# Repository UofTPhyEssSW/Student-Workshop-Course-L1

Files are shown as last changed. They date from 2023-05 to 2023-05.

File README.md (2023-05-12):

# Student-Workshop-Course-L1



<p>
This is a non-credit Introduction to Electronics Graduate course for University of Toronto, Physics Gradute students, held over four, three-hour sessions which consist of one hour of lecture and two hours of practical time.
</p>

## Course Summary

<p>
This course is an Introduction to Electronics course where the student will learn how to solder through hole and surface mount components as well as learn about data acquisition (DAQ), power supplies, digital and analog electronics circuits. During the course the students will build a single channel DAQ board that measures ambient temperature and an Arduino Uno clone, which is theirs to take home. Please note that class has a maximum of 4 students and must have a minimum of 2 students registered for the class to be held.

If the class is full and your are still interested, please add yourself to the waiting list. We will try to schedule another course as soon as possible.
</p>

<a href="https://plrs.physics.utoronto.ca/course-listing/">Available Courses</a>

# Aruduino Framework
<p>
The Arduino IDE 2 is used to demostrate the Phyduino Pico and Analog Front End board. Since these are custom boards a new board manager and libraries must be installed in the IDE for the boards to be programmed. (<a href="https://docs.arduino.cc/software/ide-v2/tutorials/ide-v2-board-manager">instructions here</a>). 
</p>

# Required Arduino Libraries 
- <a href="https://github.com/sparkfun/SparkFun_STUSB4500_Arduino_Library/tree/7f76188b7900d930aeb7908319d463b6446257c6">Sparkfun STUSB4500 Arduino library</a>
- <a href="https://github.com/UofTPhyEssSW/Student-Workshop-Course-L1/tree/main/arduino/libraries/max11635_adc">MAX11635 ADC Arduino Libray</a>
- <a href="https://github.com/UofTPhyEssSW/Student-Workshop-Course-L1/tree/main/arduino/libraries/phyduino_pico">Phyduino Board Library</a>
- <a href="https://github.com/UofTPhyEssSW/Student-Workshop-Course-L1/tree/main/arduino/libraries/Analog_Front_End_Arduino_Library">Analog Front End Arduino Library</a>
- <a href="https://github.com/mathertel/RotaryEncoder">Rotary Encoder Library</a>
# Hardware 

<p>
All circuit boards for this course were designed using <a href="https://www.kicad.org/">KiCad EDA</a> opensource software to make the schematic and PCB design files easy to access for the student. It's not requirement for the student to understand schematic symbols or PCB design the files are there for reference.
</p>

## Boards

- <a href="https://github.com/UofTPhyEssSW/Student-Workshop-Course-L1/tree/main/hardware/phyduino_pico">Phyduino Pico Microcontroller board</a>
- <a href="https://github.com/UofTPhyEssSW/Student-Workshop-Course-L1/tree/main/hardware/analog_front_end_shield">Analog Front End board</a>

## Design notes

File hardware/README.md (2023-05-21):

# Course Hardware
<p>
There are two boards that are built by the students in the course. The first is the Analog Front End PCB with helps the 
student practise through hole soldering. The second is the Phyduino Pico PCB which continues the soldering training, 
learning how solder surface mount components.
</p>
<p>
Each board is designed using open source software <a href="https://www.kicad.org/">KiCAD EDA</a> design software.
</p>

# Analog Front End PCB
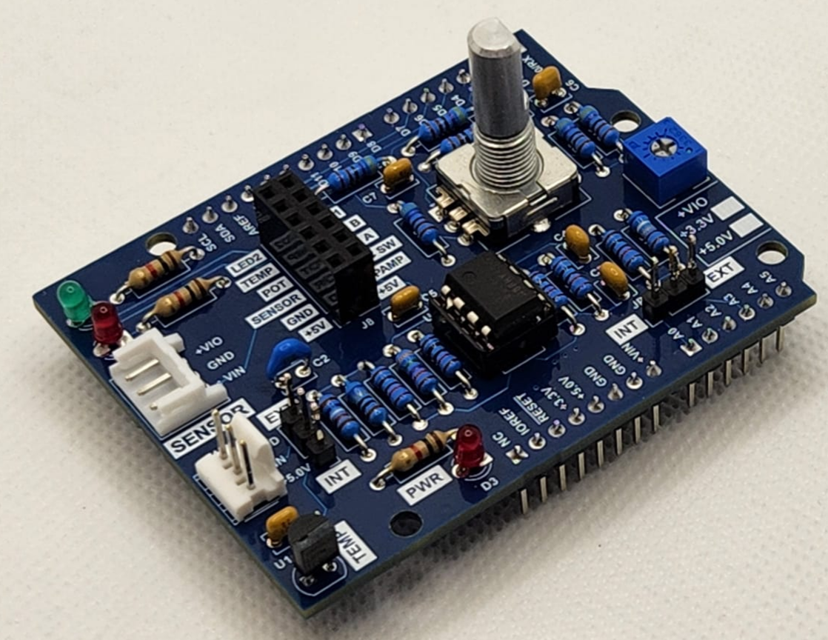
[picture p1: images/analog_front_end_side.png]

<p>
The Analog Front End (AFE) Board is a demonstration board that is specifically designed to interface with the Phyduino 
Pico board, though it is compatible with other Arduino boards. It is used to train students on good through hole 
soldering techniques, basic data acquisition (DAQ) techniques, and digital interface.
</p>
<p>
The AFE board has a <a href="https://www.ti.com/product/LMT84/part-details/LMT84LPM">LMT84LPM</a> temperature sensor with 
an analog output. Its temperature range is –50°C to 150°C. This sensor is used to demonstrate DAQ circuit design and step 
necessary to acquire data from analog signal. The temperature signal is output on A0 or A3 depending on JP2 jumper position. 
Other than the temperature signals the AFE board also outputs analog signals from the sensor connector (J2), the potentiometer (RV1), 
and the voltage output of the LMT84 (U1) temperature sensor before signal conditioning.
</p>
<p>
In addition to analog signals the AFE board also has digital input and output. The rotary encoder (ENC1) in used for 
digital input which can be used to control parameter within the Phyduino Pico program being run. LED's D1 and D2 can be 
used to output current status of the program or just flash on and off to indicate the program has not froze.
</p>

# Phyduino Pico PCB
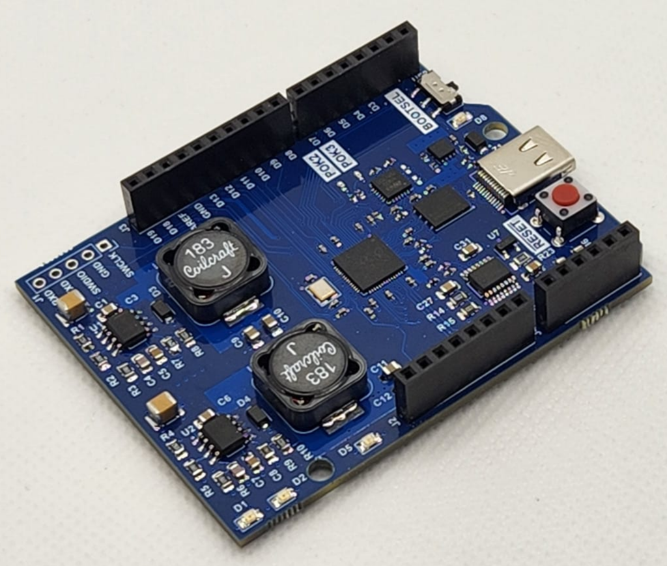
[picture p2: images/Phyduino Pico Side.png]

<p>
The Phyduino Pico is an Arduino compatible microcontroller board the can be programmed using the <a href="https://docs.arduino.cc/software/ide-v2">Arduino IDE</a>. The Phyduino Pico uses the <a href="https://www.raspberrypi.com/products/rp2040/">Raspberry PI Pico micorcontroller</a> (RP2040) with 2 ARM Cortex-M0+ processors (133MHz) and 264KB of RAM. All programming code is stored in an external 16MB flash chip that can be both programming memory and solid state drive. The microcontroller can be program in C/C++ or <a href="https://www.raspberrypi.com/documentation/microcontrollers/micropython.html">MicroPython</a>. This course only shows examples with C/C++ programming, however there are many tutorials online for programming the RP2040 with MicroPython. 
</p>
<p>
The Phyduino Pico board is power using the USB Power delivery through the USB-C connector. Power delivery is negotiated throught the CC lines on the USB-C connector using the <a href="https://www.st.com/en/interfaces-and-transceivers/stusb4500.html">STUSB4500</a> USB PD controller. The STUSB4500 is programmed to negotiated for 3 power profiles, +5.0V(default), +9.0V, and +20V. The controller will try to negotiate for the high one available. By default all power delivery devices must have at least one profile by default +5.0V. The USB-C connector is used to both power and communicate with the board. Power for the board is regulated through 2, <a href="https://www.ti.com/product/TPS54231?dcmp=dsproject&hqs=td&#doctype2">TPS54231</a> DC/DC converters that steps down the USB VBus voltage to +3.3V and +5.0V.The +3.3V DC/DC regulator is enabled when the USB VBus voltage is above 4.5V. The +5.0V regulator is enabled when USB VBus voltage is above 7.0V. Each power rail on the board the has a led to indicate if the power is active, red for VBus, yellow for +3.3V and green for +5.0V. This allows the user to visual assess which power rails are active. If the the green led is off the USB-PD controller could not negotiate a high power then the default +5.0V. Power is output from the board through J2. +VUSB on J2 is connected directly to the USB VBus if the connected shield board is cannot accommodate the voltage here concider using a linear regulator to being down the voltage required by the shield board. 
</p>
<p>
All connector IO's are compatible with <a href="https://content.arduino.cc/assets/A000066-full-pinout.pdf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.">Arduino UNO Rev3</a> pin outs. The digital IO pins are +3.3V digital IO tolerant. Do not use shield boards that use IO voltage above +3.3V you will damage the RP2040 IO's. The Analog input pins are broken into 2 groups, internal (A0 - A2) and external (A3 - A5). The internal analog signals are connected to the RP2040 microcontroller's internal 12bit 500KSps ADC. The voltage reference for the RP2040 internal ADC is +3.3V so the <b>maximum measurable voltage is +3.3V</b>. The external signals is connected to the Analog Devices <a href="https://www.analog.com/en/products/max11635.html">MAX11635</a> 12bit 300Ksps ADC. The voltage reference for the MAX11635 is 2.048V so the <b>maximum measurable voltage is +2.048V</b>. Exceed any of this maximum voltage for any analog input group with damage either the RP2040 or MAX11635.
</p>

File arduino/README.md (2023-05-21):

# Arduino IDE Framework

The Arduino IDE Frame has come alone way since it's introduction in the late 2000's. It is a very flexible platform that 
allows users to add custom libraries and board managers that give access to the simpliest to very complex microcontroller 
platforms. This makes it a good platform to introduce programming concepts.

## Installing board managers

<p>
The board manager was created by Earle F. Philhower since Arduino or the Raspberry PI foundation have not released a
version of their own. It comes highly recommended over other board managers for the Raspberry PI Pico microcontroller 
and will be used for this course. Instructions for installing the board manager are on the board manager project 
<a href="https://github.com/earlephilhower/arduino-pico.git">GitHub page</a>. Please refer to it when installing the 
board manager. 
</p>

## Installing libraries 

<p>
There are 5 libraries that need to be added to the Arduino IDE for coding with the Phyduino Pico.
</p>

1. <a href="https://github.com/sparkfun/SparkFun_STUSB4500_Arduino_Library/tree/7f76188b7900d930aeb7908319d463b6446257c6">Sparkfun STUSB4500 Arduino Library</a>
2. <a href="https://github.com/UofTPhyEssSW/Student-Workshop-Course-L1/tree/main/arduino/libraries/max11635_adc">MAX11635 ADC Arduino Library</a>
3. <a href="https://github.com/UofTPhyEssSW/Student-Workshop-Course-L1/tree/main/arduino/libraries/phyduino_pico">Phyduino Pico Library.</a>
4. <a href="https://github.com/UofTPhyEssSW/Student-Workshop-Course-L1/tree/main/arduino/libraries/Analog_Front_End_Arduino_Library">Analog Front End Arduino Library</a>
5. <a href="https://github.com/mathertel/RotaryEncoder">Rotary Encoder Library</a>

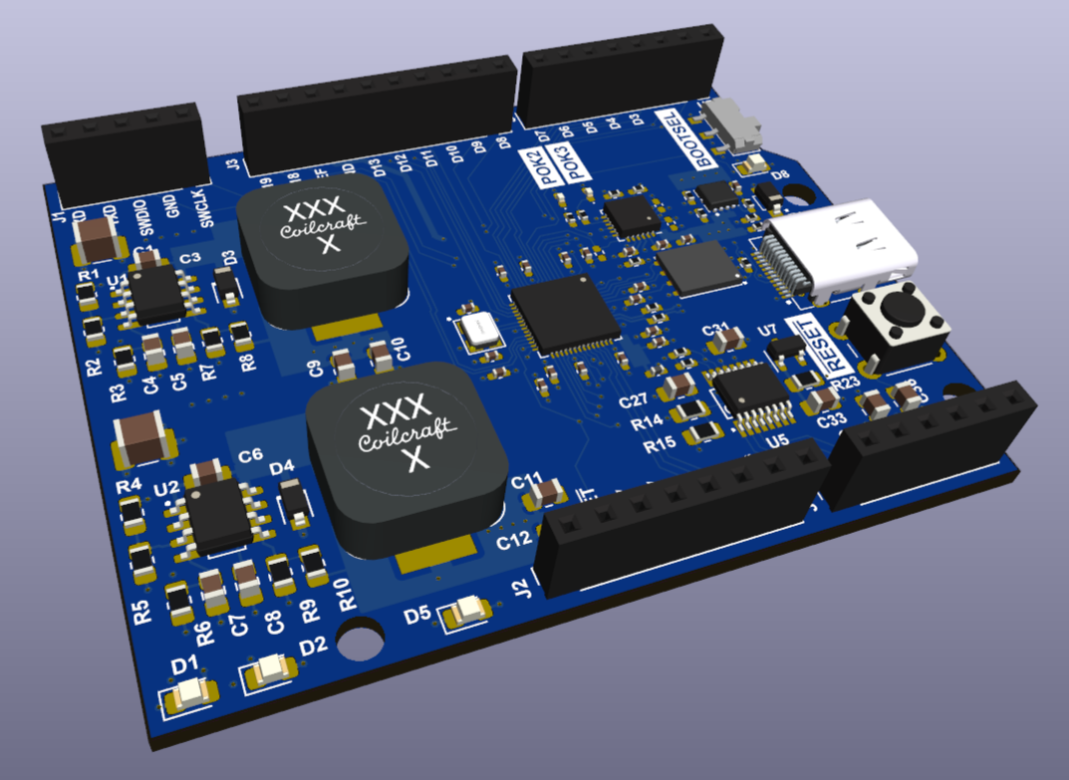
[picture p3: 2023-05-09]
images/Phyduino_Pico_RevC.png

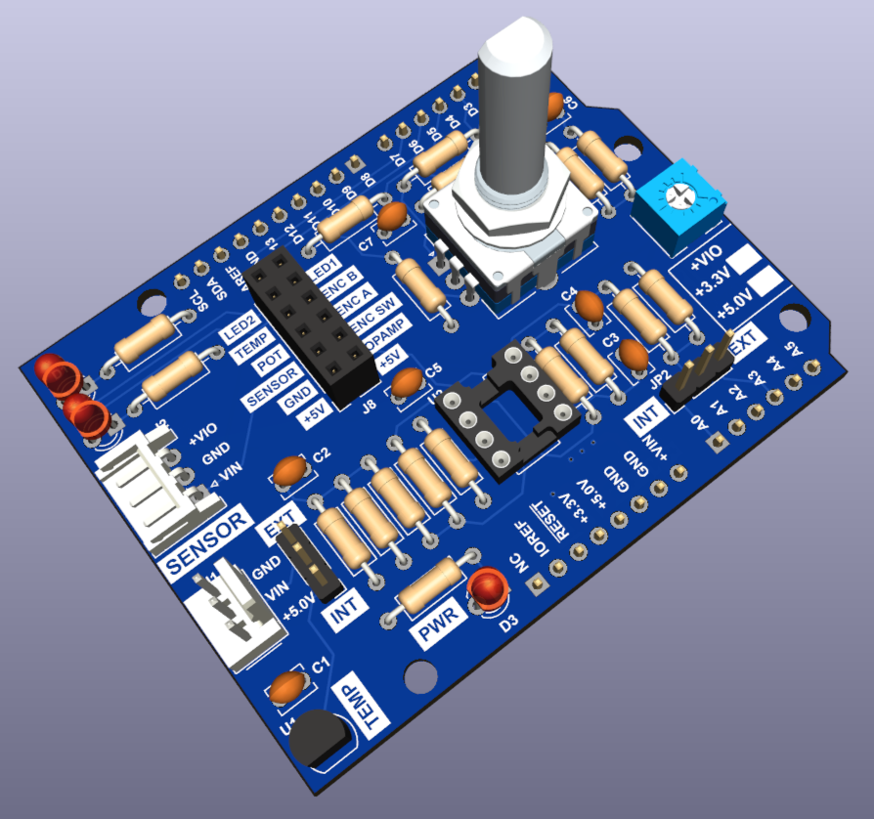
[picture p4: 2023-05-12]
images/AFE_Shield_RevC.png

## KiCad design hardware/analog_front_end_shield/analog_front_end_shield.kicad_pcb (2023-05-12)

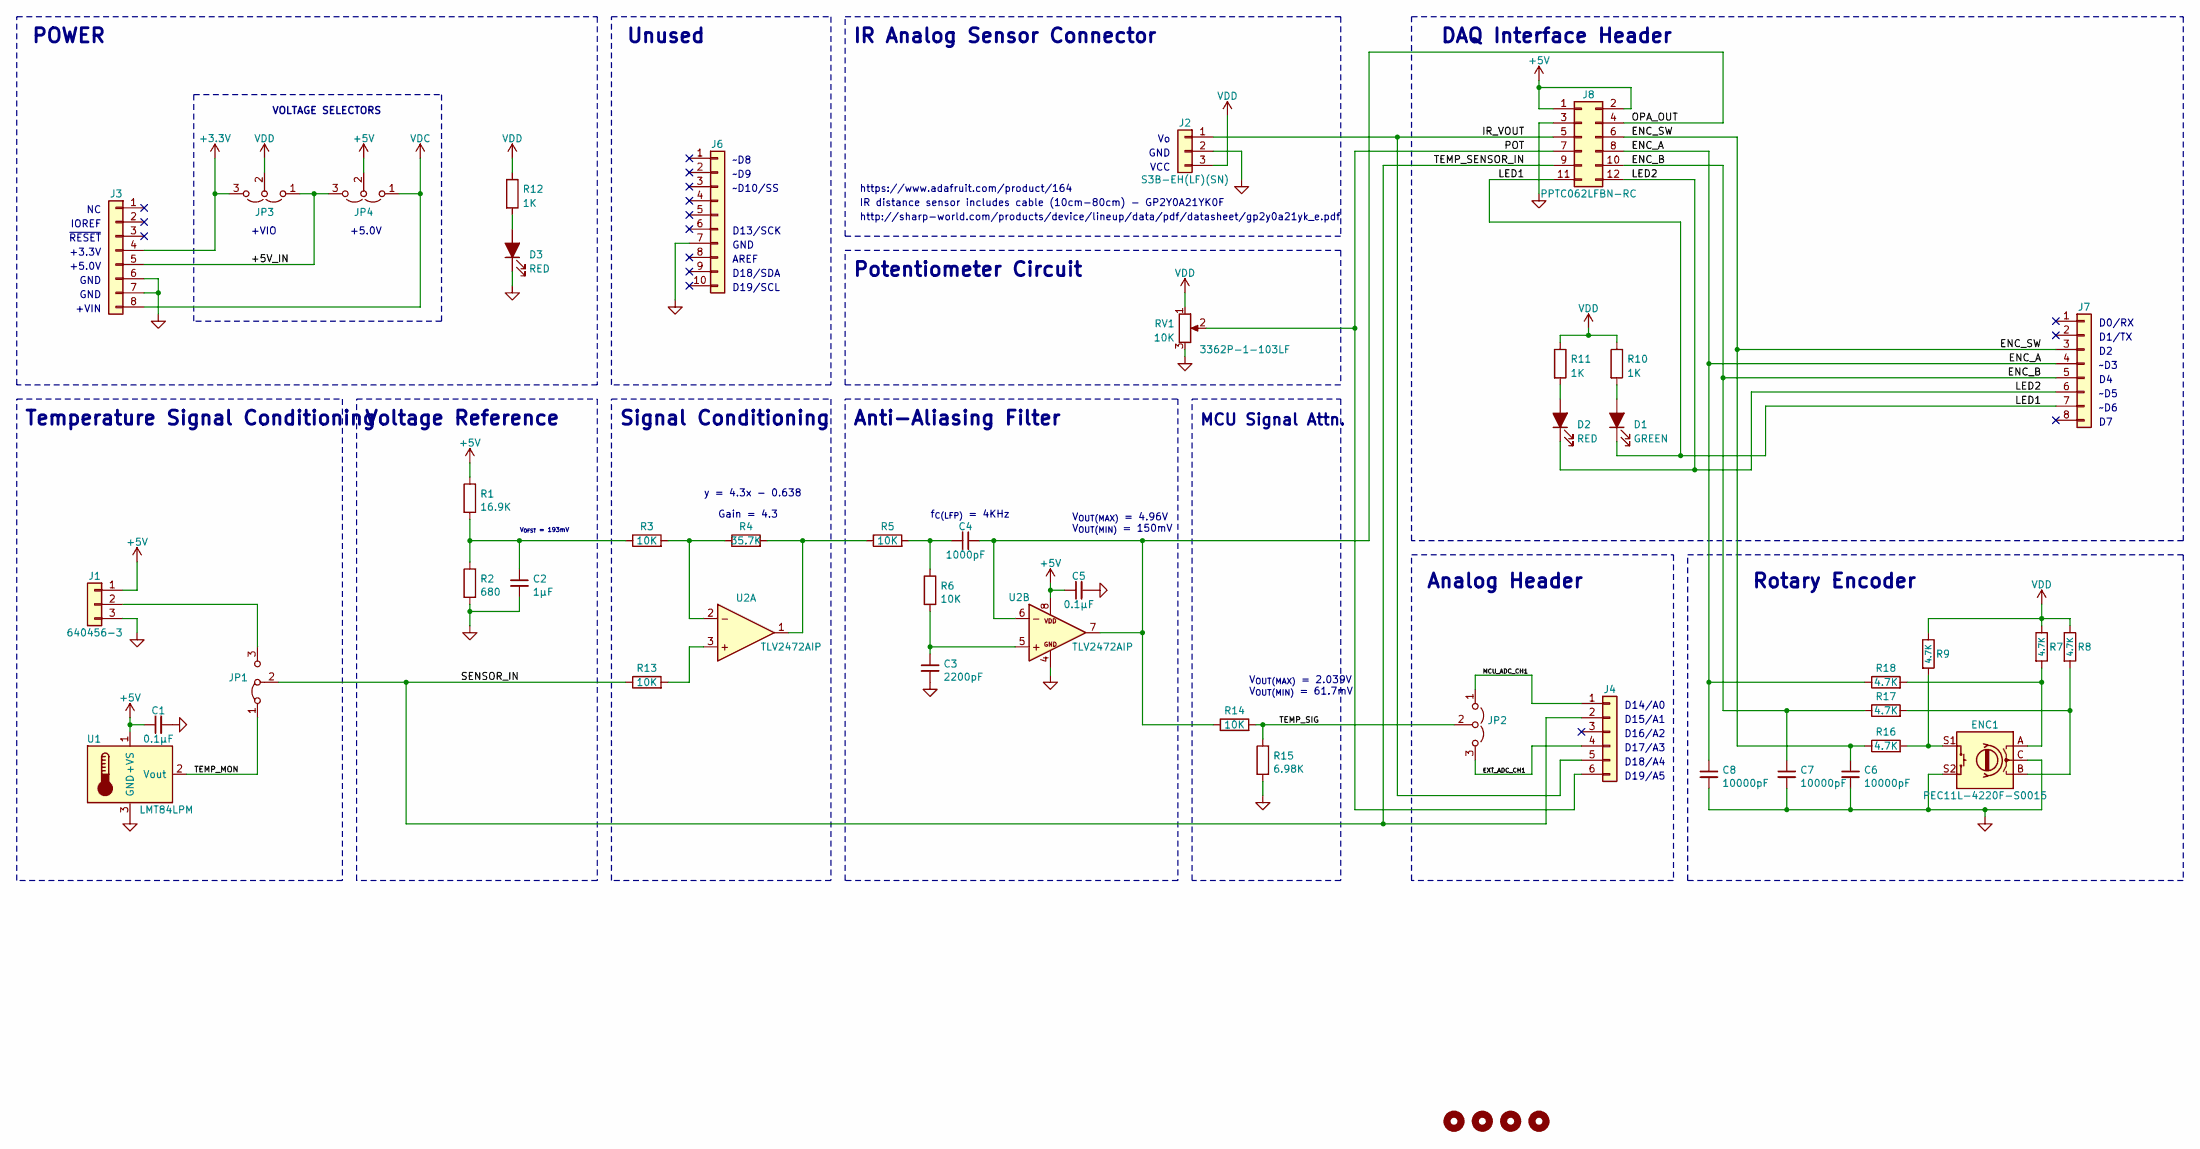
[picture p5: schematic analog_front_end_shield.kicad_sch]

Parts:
C1, C5: 0.1µF; C_Disc_D3.8mm_W2.6mm_P2.50mm
C2: 1µF; C_Disc_D3.8mm_W2.6mm_P2.50mm
C3: 2200pF; C_Disc_D3.8mm_W2.6mm_P2.50mm
C4: 1000pF; C_Disc_D3.8mm_W2.6mm_P2.50mm
C6, C7, C8: 10000pF; C_Disc_D3.8mm_W2.6mm_P2.50mm
D1: GREEN; LED_D3.0mm
D2, D3: RED; LED_D3.0mm
ENC1: PEC11L-4220F-S0015; RotaryEncoder_Alps_EC12E-Switch_Vertical_H20mm_CircularMoun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
H1, H2, H3, H4: MountingHole; MountingHole_3.2mm_M3
J1: 640456-3; Molex_KK-254_AE-6410-03A_1x03_P2.54mm_Vertical
J2: S3B-EH(LF)(SN); JST_EH_S3B-EH_1x03_P2.50mm_Horizontal
J3, J7: Conn_01x08; PinHeader_1x08_P2.54mm_Vertical
J4: Conn_01x06; PinHeader_1x06_P2.54mm_Vertical
J6: Conn_01x10; PinHeader_1x10_P2.54mm_Vertical
J8: PPTC062LFBN-RC; PinSocket_2x06_P2.54mm_Vertical
JP1: Jumper_3_Bridged12; PinHeader_1x03_P2.54mm_Vertical
JP2: Jumper_3_Open; PinHeader_1x03_P2.54mm_Vertical
JP3, JP4: Jumper_3_Open; SolderJumper-3_P2.0mm_Open_TrianglePad1.0x1.5mm
R1: 16.9K; R_Axial_DIN0207_L6.3mm_D2.5mm_P10.16mm_Horizontal
R2: 680; R_Axial_DIN0207_L6.3mm_D2.5mm_P10.16mm_Horizontal
R3, R5, R6, R13, R14: 10K; R_Axial_DIN0207_L6.3mm_D2.5mm_P10.16mm_Horizontal
R4: 35.7K; R_Axial_DIN0207_L6.3mm_D2.5mm_P10.16mm_Horizontal
R7, R8, R9, R16, R17, R18: 4.7K; R_Axial_DIN0207_L6.3mm_D2.5mm_P10.16mm_Horizontal
R10, R11, R12: 1K; R_Axial_DIN0207_L6.3mm_D2.5mm_P10.16mm_Horizontal
R15: 6.98K; R_Axial_DIN0207_L6.3mm_D2.5mm_P10.16mm_Horizontal
RV1: 10K; TRIM_3362P-1-103LF
U1: LMT84LPM; TO-92
U2: TLV2472AIP; DIP-8_W7.62mm

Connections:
+3V3: J3.4, JP3.3 (B)
+5V: C1.1, C5.1, J1.1, J8.1, J8.2, JP4.2 (C), R1.1, U1.1 (+VS), U2.8 (V+)
/+5V_IN: J3.5, JP3.1 (A), JP4.3 (B)
/ENC_A: C8.1, J7.4, J8.8, R18.1
/ENC_B: C7.1, J7.5, J8.10, R17.1
/ENC_SW: C6.1, J7.3, J8.6, R16.1
/EXT_ADC_CH1: J4.4, JP2.3 (B)
/IR_VOUT: J2.1, J4.5, J8.5
/LED1: D1.1 (K), J7.7, J8.11
/LED2: D2.1 (K), J7.6, J8.12
/MCU_ADC_CH1: J4.1, JP2.1 (A)
/OPA_OUT: C4.2, J8.4, R14.1, U2.6 (-), U2.7 (OUT)
/POT: J4.6, J8.7, RV1.2
/SENSOR_IN: J4.2, J8.9, JP1.2 (C), R13.1
/TEMP_MON: JP1.1 (A), U1.2 (Vout)
/TEMP_SIG: JP2.2 (C), R14.2, R15.1
GND: C1.2, C2.2, C3.2, C5.2, C6.2, C7.2, C8.2, D3.1 (K), ENC1.C, ENC1.S2, J1.3, J2.2, J3.6, J3.7, J6.7, J8.3, R2.2, R15.2, RV1.3, U1.3 (GND), U2.4 (GND)
unnamed: C2.1, R1.2, R2.1, R3.1
unnamed: C4.1, R5.2, R6.1
unnamed: D1.2 (A), R10.2
unnamed: D2.2 (A), R11.2
unnamed: D3.2 (A), R12.2
unnamed: ENC1.A, R7.2, R18.2
unnamed: ENC1.B, R8.2, R17.2
unnamed: ENC1.S1, R9.2, R16.2
unnamed: J1.2, JP1.3 (B)
unnamed: R13.2, U2.3 (+)
unnamed: R3.2, R4.1, U2.2 (-)
unnamed: R4.2, R5.1, U2.1 (OUT)
unnamed: C3.1, R6.2, U2.5 (+)
VDC: J3.8, JP4.1 (A)
VDD: J2.3, JP3.2 (C), R7.1, R8.1, R9.1, R10.1, R11.1, R12.1, RV1.1

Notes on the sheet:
Signal Conditioning
~D8
AREF
DAQ Interface Header
Anti-Aliasing Filter
D13/SCK
IOREF
VOLTAGE SELECTORS
V_{OUT(MAX)} = 2.039V V_{OUT(MIN)} = 61.7mV
D14/A0
Voltage Reference
~D10/SS
~D9
D17/A3
+5.0V
https://www.adafruit.com/product/164
GND
D19/A5
~D5
D19/SCL
V_{OFST} = 193mV
Unused
~{RESET}
D18/A4
~D6
http://sharp-world.com/products/device/lineup/data/pdf/datasheet/gp2y0a21yk_e.pdf
D16/A2
Temperature Signal Conditioning
f_{C(LFP)} = 4KHz
D1/TX
+VIN
IR Analog Sensor Connector
D18/SDA
~D3
Rotary Encoder
VCC
MCU Signal Attn.
POWER
IR distance sensor includes cable (10cm-80cm) - GP2Y0A21YK0F
D0/RX

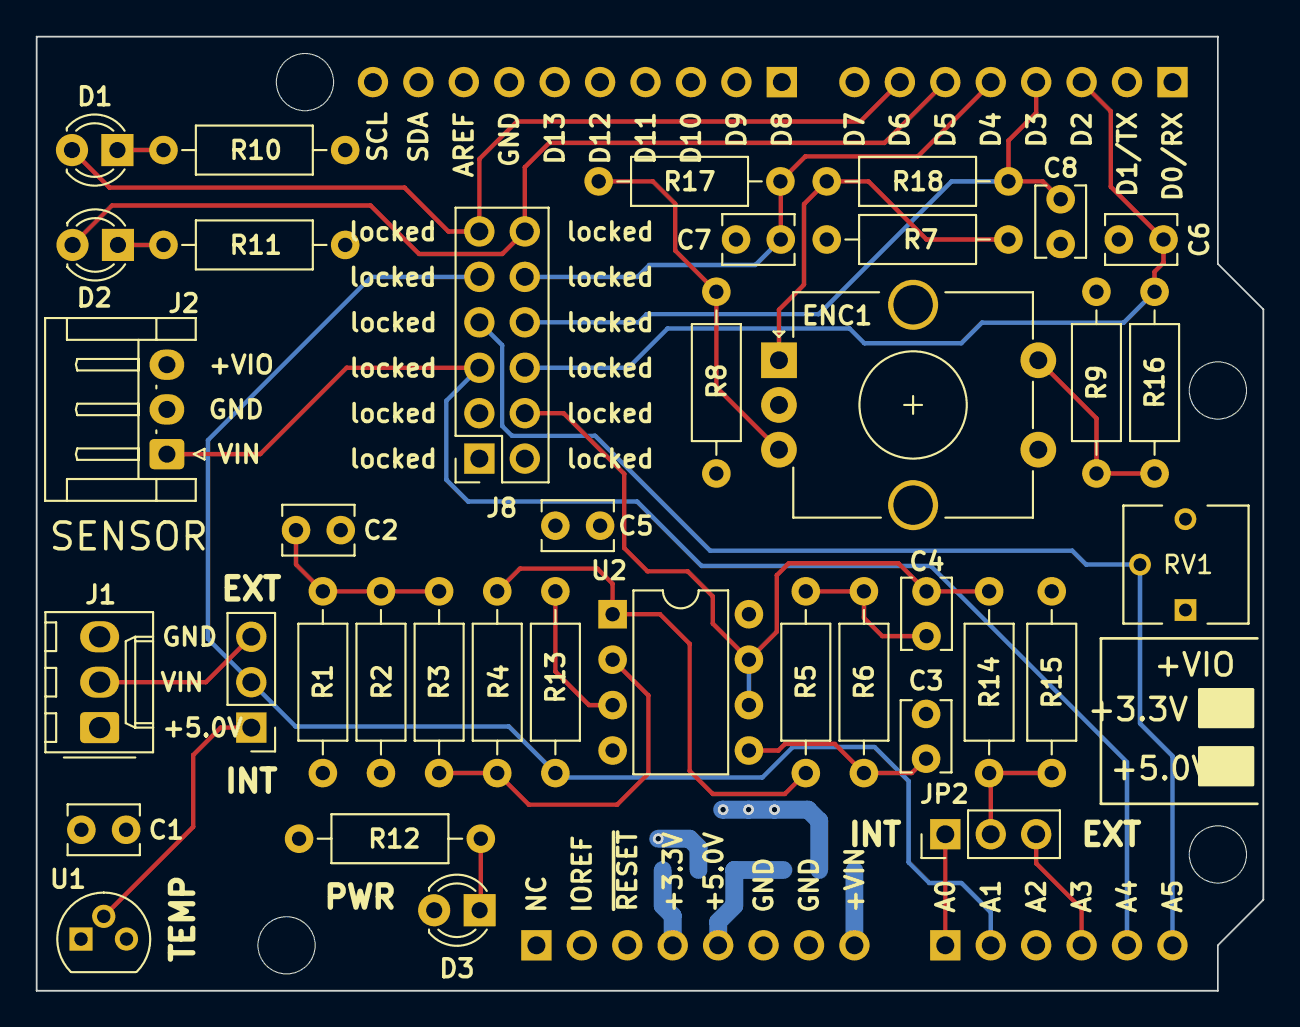
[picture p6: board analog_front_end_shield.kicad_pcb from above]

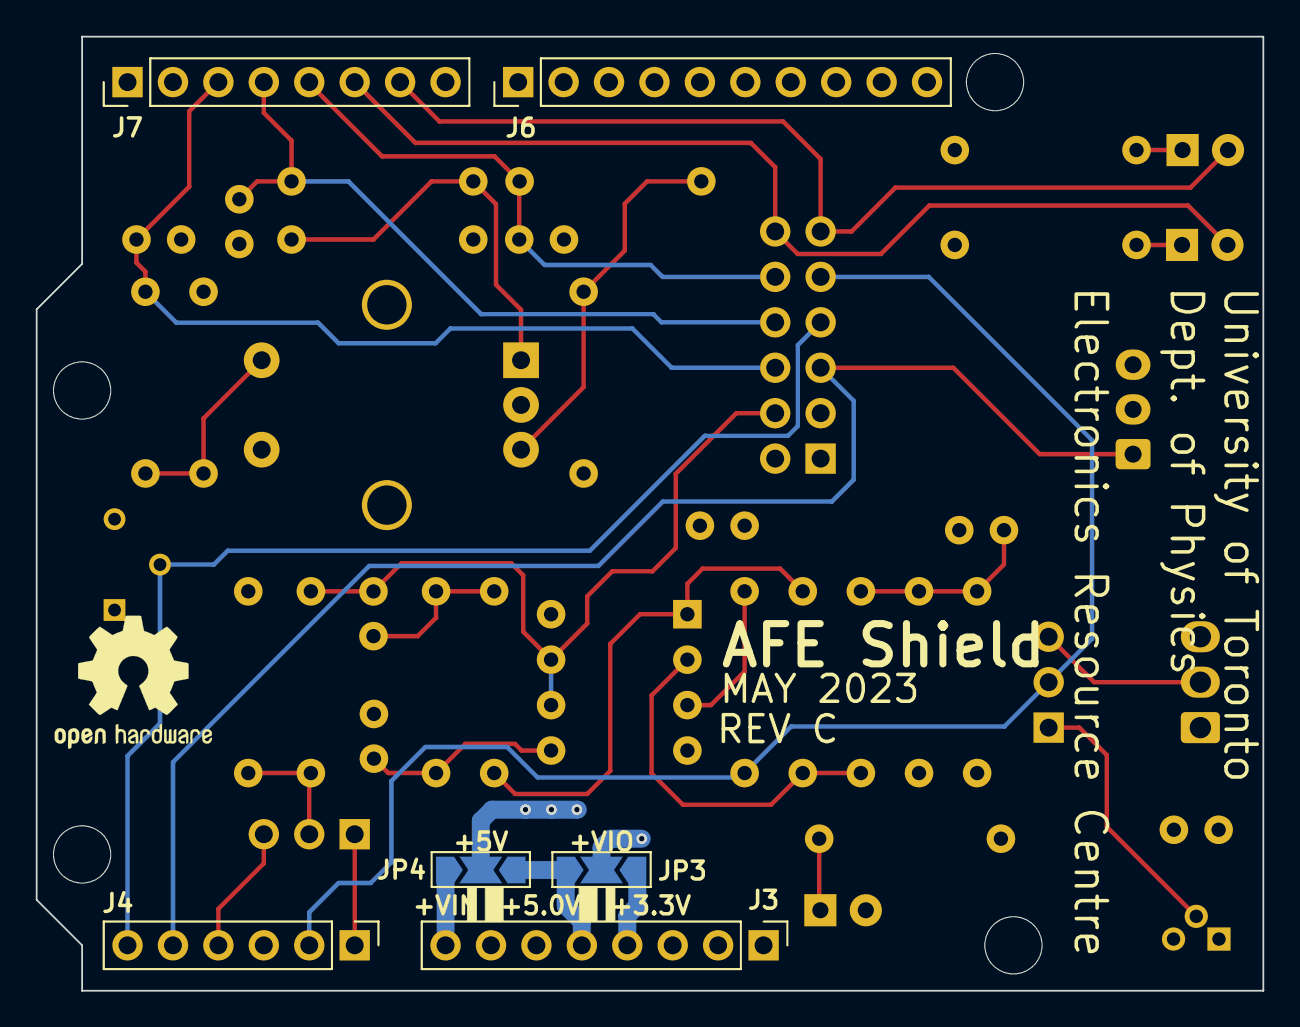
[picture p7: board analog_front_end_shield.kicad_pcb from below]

Board: 4 copper layers, 68.6 x 53.3 mm, 48 parts (6 on the bottom side), 32 nets.

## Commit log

2023-03-30 Initial commit, hardware and arduino
    Initial commit of hardware design files, Arduino libraries and board manger repositories.
    [phyduino_pico.kicad_sch]
2023-03-30 Add submodules
    Changed the file directory for the arduino folder and added IDE board manager for RP2040
2023-03-30 Update max11635.h
    testing arduino library, making changes to errors.
2023-05-08 Hardware projects added
    Final boards added to repository : Phyduino Pico Rev C and Analog Front End Rev C. includes symbol and front print libraries for each project.
    [analog_front_end_shield.kicad_pcb, analog_front_end_shield.kicad_sch, phyduino_pico.kicad_sch]
2023-05-09 Add Arduino libraries for Phyduino Pico
2023-05-09 Fixed bugs and tested MAX11635 ADC Arduino Library
    Fixed bugs in library and tested. Ready for publishing.
2023-05-10 Phyduino library bug fixes and formatting
    Fixed external ADC initialization issue. Removed analog front end example; moving it to another library.
2023-05-12 Added Analog Front End library
    Initial commit for the AFE shield Arduino library
2023-05-12 Part Number update
    Updated part numbers
    [phyduino_pico.kicad_sch]
2023-05-12 AFE board version correction
    [analog_front_end_shield.kicad_pcb, analog_front_end_shield.kicad_sch]
2023-05-12 Added submodule Rotary Encoder Library
2023-05-15 Add .ZIP Library files for non-registered Arduino Libraries
    update .gitignore as well.
2023-05-19 Update resistor values for amplifier circuit.
    [analog_front_end_shield.kicad_sch]
2023-05-20 Added board pictures
2023-05-21 Add automatic library python script
    added python script to automatically update/create Arduino IDE libraries need for the course.
2023-10-04 MAX11635 ADC library code update and added example
2024-02-01 Phyduino PICO KiCAD project updated, REV D
    [phyduino_pico.kicad_sch]
2024-02-01 MAX11635 ADC library update
2024-02-01 Phyduino Pico library update
